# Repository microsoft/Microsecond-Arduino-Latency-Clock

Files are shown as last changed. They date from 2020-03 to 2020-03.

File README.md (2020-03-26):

# Microsecond Arduino Due Code and Schematics

Microsecond Arduino Due Code and Schematics accompanying the paper presented in IEEE VR 2020 "Measuring System Visual Latency through Cognitive Latency on Video See-Through AR devices" [1]
https://www.microsoft.com/en-us/research/publication/measuring-system-visual-latency-through-cognitive-latency-on-video-see-through-ar-devices/

The clock starts from zero and continues to displayelapsed time since the device was powered on. The LED turn-on andturn-off time is sub-microsecond [2], therefore we know that ourclock is sufficient for at least 0.1 millisecond measurements as theLEDs turn on and off faster than we are updating the digit segments.

This clock can be then visualized through an external observer [3] using high refresh cameras.

[1] Gruen, R., Ofek, E., Steed, A., Gal, R., Sinclair, M., & Gonzalez-Franco, M. (2020) Measuring System Visual Latency through Cognitive Latency on Video See-Through AR devices. IEEE VR 2020

[2] Lee,T. P. (1975) Effect of junction capacitance on the rise time of led’s and onthe turn-on delay of injection lasers. The Bell System Technical Journal,54(1):53–68, Jan 1975.

[3] Wu, W., Dong, Y., & Hoover, A. (2013). Measuring digital system latency from sensing to actuation at continuous 1-ms resolution. Presence: Teleoperators and Virtual Environments, 22(1), 20-35.

Schematics created with Eagle v 9.5.2.



# Contributing

This project welcomes contributions and suggestions.  Most contributions require you to agree to a
Contributor License Agreement (CLA) declaring that you have the right to, and actually do, grant us
the rights to use your contribution. For details, visit https://cla.opensource.microsoft.com.

When you submit a pull request, a CLA bot will automatically determine whether you need to provide
a CLA and decorate the PR appropriately (e.g., status check, comment). Simply follow the instructions
provided by the bot. You will only need to do this once across all repos using our CLA.

This project has adopted the [Microsoft Open Source Code of Conduct](https://opensource.microsoft.com/codeofconduct/).
For more information see the [Code of Conduct FAQ](https://opensource.microsoft.com/codeofconduct/faq/) or
contact [opencode@microsoft.com](mailto:opencode@microsoft.com) with any additional questions or comments.

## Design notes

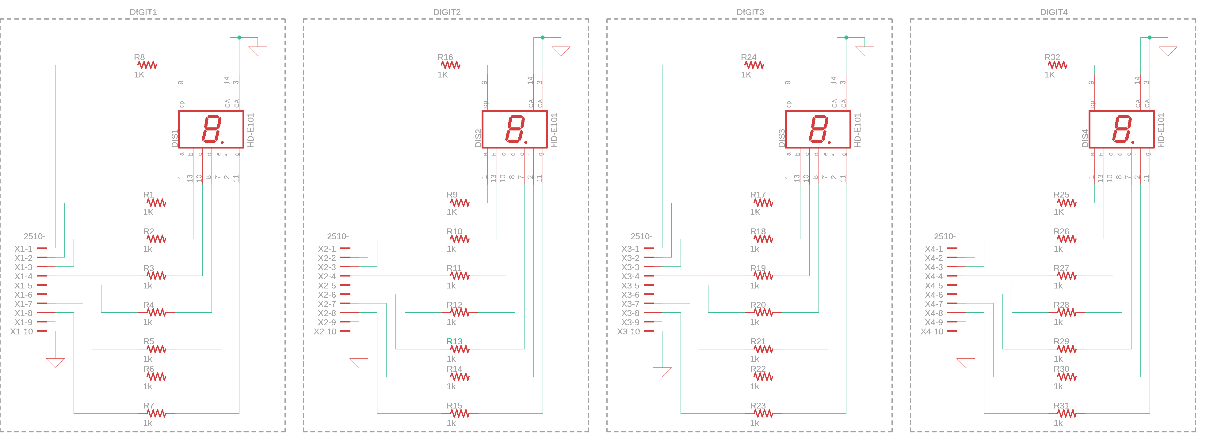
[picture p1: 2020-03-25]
Microsecond clock LEDs - Circuit Diagram.png

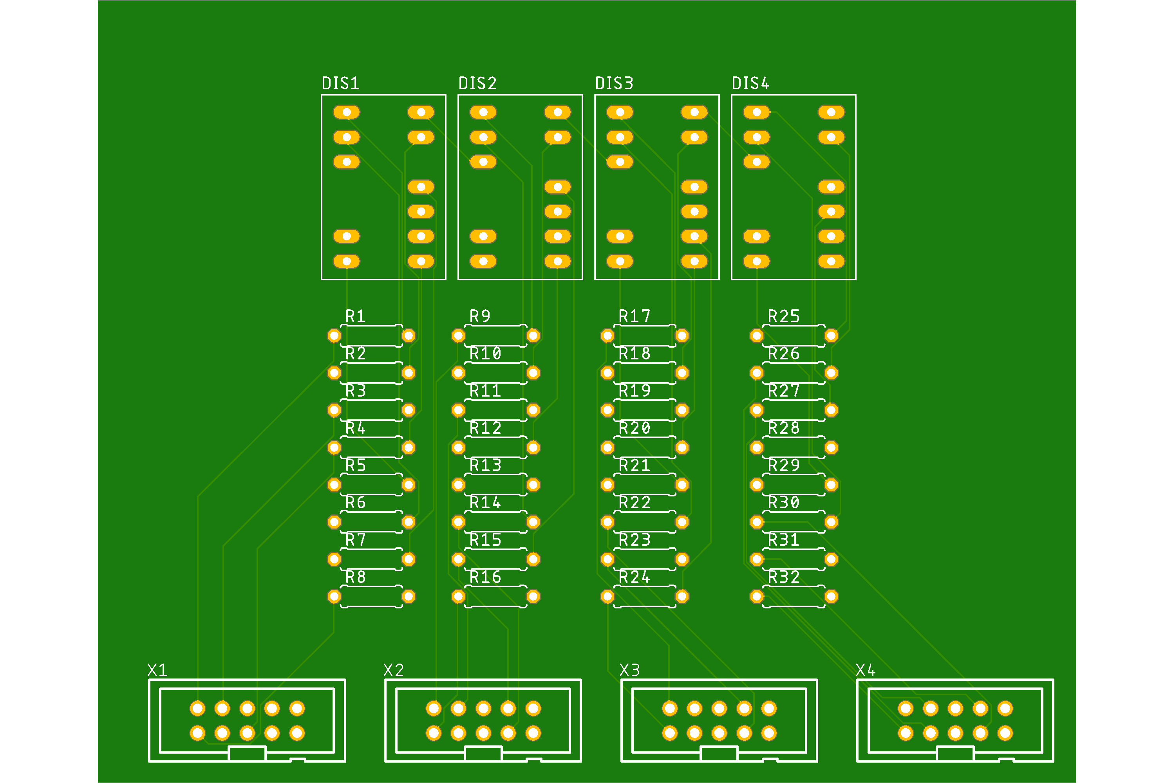
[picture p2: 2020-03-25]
Microsecond clock LEDs - PCB.png

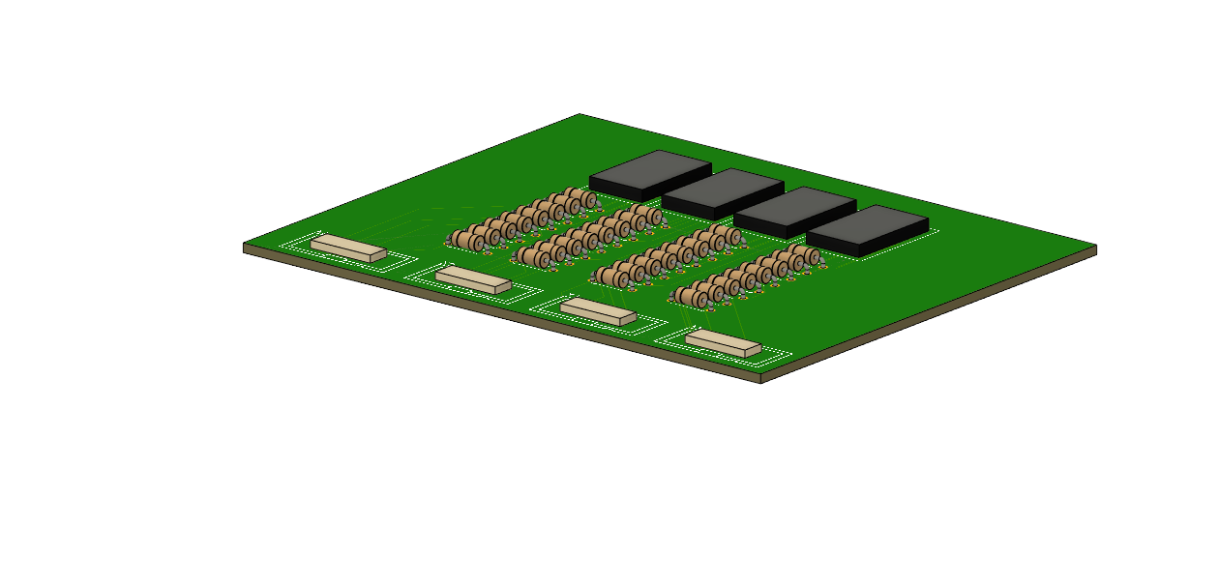
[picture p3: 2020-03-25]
Microsecond clock LEDs - CAD Rendering.png

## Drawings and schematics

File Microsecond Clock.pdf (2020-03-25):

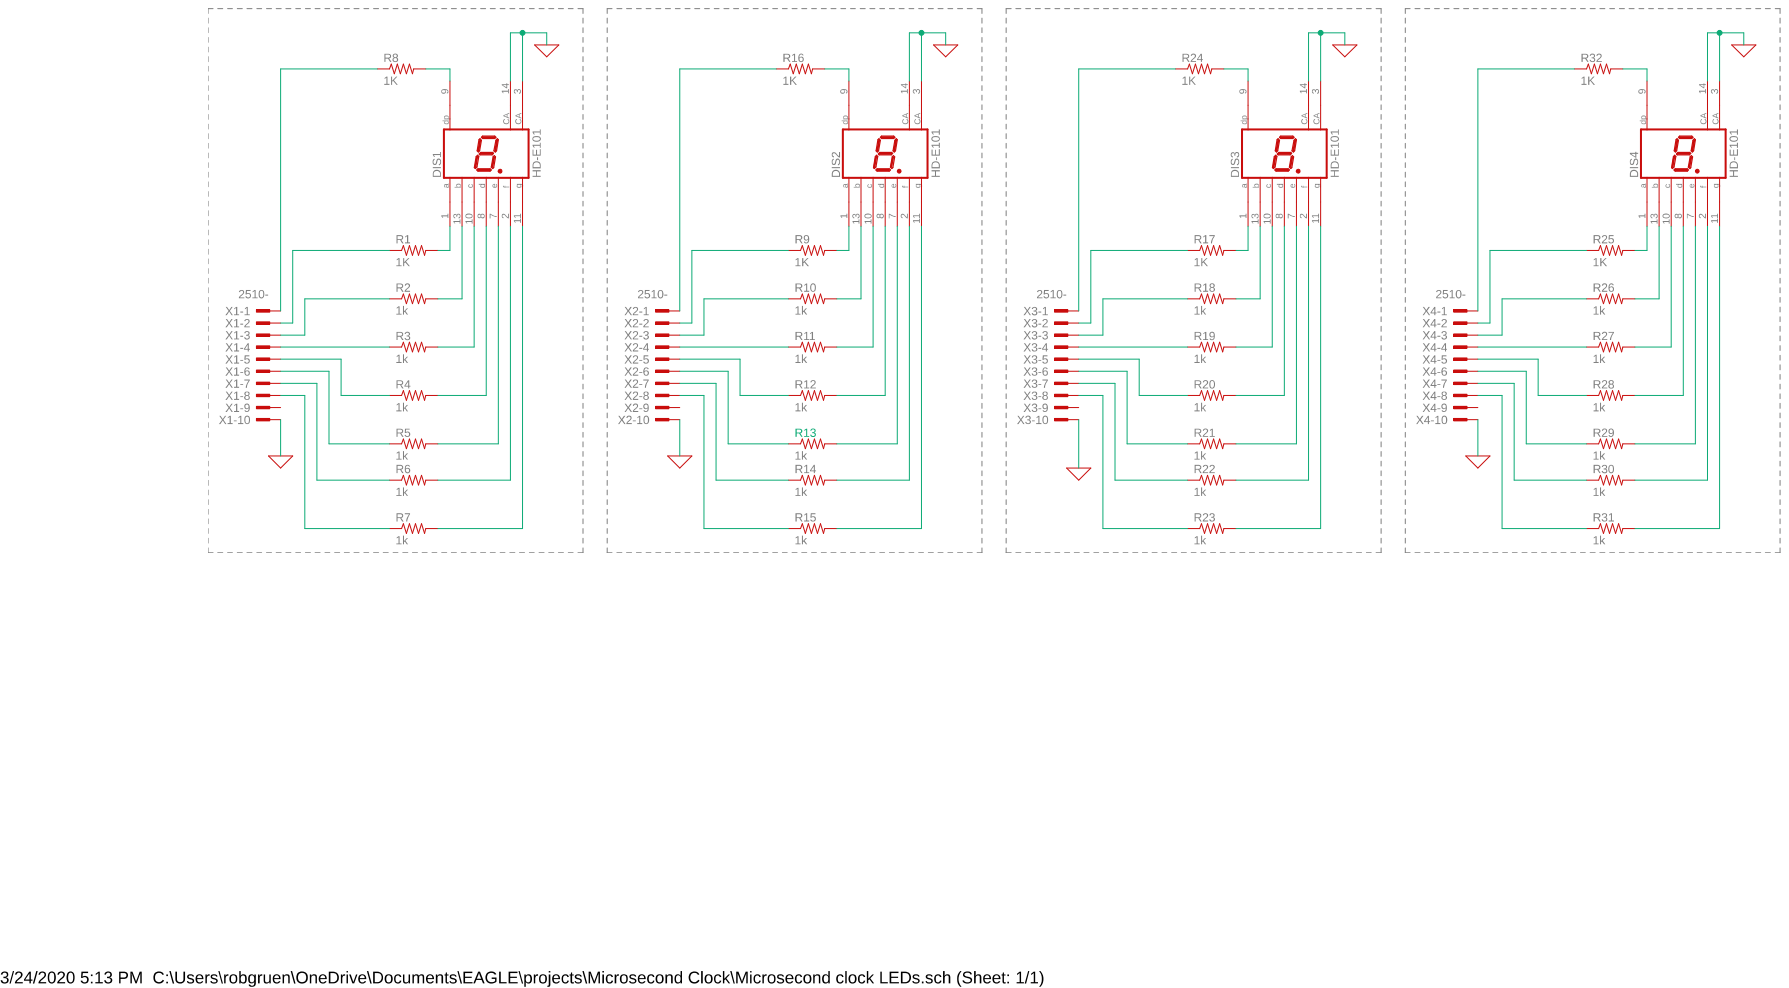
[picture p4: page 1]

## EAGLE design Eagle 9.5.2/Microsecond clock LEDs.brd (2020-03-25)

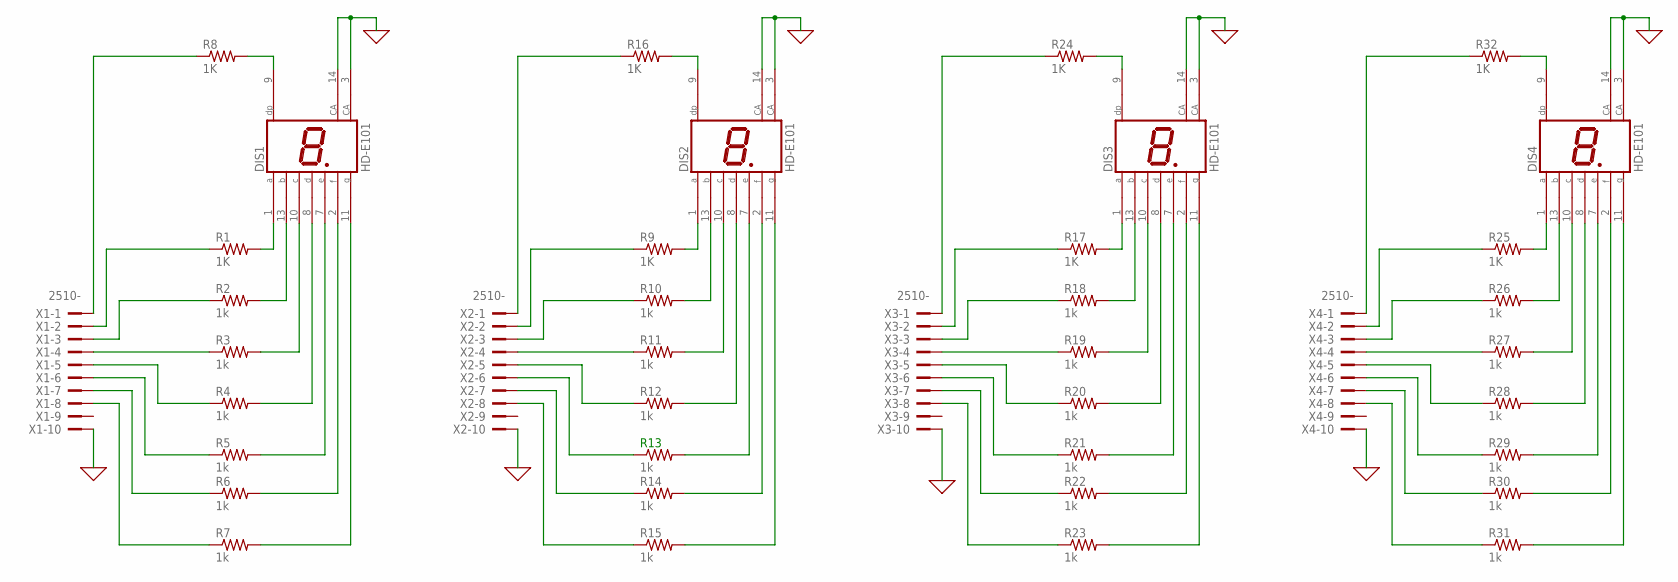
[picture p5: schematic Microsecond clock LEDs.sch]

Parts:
DIS1, DIS2, DIS3, DIS4: HD-E101; HDSP-I
R1, R8, R9, R16, R17, R24, R25, R32: 1K; 0207/7
R2, R3, R4, R5, R6, R7, R10, R11, R12, R13, R14, R15, R18, R19, R20, R21, R22, R23, R26, R27, R28, R29, R30, R31: 1k; 0207/7
X1, X2, X3, X4: 2510-; PAK100/2500-10

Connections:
0: DIS1.3 (CA), DIS1.14 (CA), DIS2.3 (CA), DIS2.14 (CA), DIS3.3 (CA), DIS3.14 (CA), DIS4.3 (CA), DIS4.14 (CA), X1.10, X2.10, X3.10, X4.10
unnamed: DIS1.1 (A), R1.2
unnamed: DIS1.13 (B), R2.2
unnamed: DIS1.10 (C), R3.2
unnamed: DIS1.8 (D), R4.2
unnamed: DIS1.7 (E), R5.2
unnamed: DIS1.2 (F), R6.2
unnamed: DIS1.11 (G), R7.2
unnamed: DIS1.9 (DP), R8.2
unnamed: R8.1, X1.1
unnamed: R1.1, X1.2
unnamed: R2.1, X1.3
unnamed: R3.1, X1.4
unnamed: R4.1, X1.5
unnamed: R5.1, X1.6
unnamed: R6.1, X1.7
unnamed: R7.1, X1.8
unnamed: DIS2.1 (A), R9.2
unnamed: DIS2.13 (B), R10.2
unnamed: DIS2.10 (C), R11.2
unnamed: DIS2.8 (D), R12.2
unnamed: DIS2.7 (E), R13.2
unnamed: DIS2.2 (F), R14.2
unnamed: DIS2.11 (G), R15.2
unnamed: DIS2.9 (DP), R16.2
unnamed: R16.1, X2.1
unnamed: R9.1, X2.2
unnamed: R10.1, X2.3
unnamed: R11.1, X2.4
unnamed: R12.1, X2.5
unnamed: R13.1, X2.6
unnamed: R14.1, X2.7
unnamed: R15.1, X2.8
unnamed: DIS3.1 (A), R17.2
unnamed: DIS3.13 (B), R18.2
unnamed: DIS3.10 (C), R19.2
unnamed: DIS3.8 (D), R20.2
unnamed: DIS3.7 (E), R21.2
unnamed: DIS3.2 (F), R22.2
unnamed: DIS3.11 (G), R23.2
unnamed: DIS3.9 (DP), R24.2
unnamed: R24.1, X3.1
unnamed: R17.1, X3.2
unnamed: R18.1, X3.3
unnamed: R19.1, X3.4
unnamed: R20.1, X3.5
unnamed: R21.1, X3.6
unnamed: R22.1, X3.7
unnamed: R23.1, X3.8
unnamed: DIS4.1 (A), R25.2
unnamed: DIS4.13 (B), R26.2
unnamed: DIS4.10 (C), R27.2
unnamed: DIS4.8 (D), R28.2
unnamed: DIS4.7 (E), R29.2
unnamed: DIS4.2 (F), R30.2
unnamed: DIS4.11 (G), R31.2
unnamed: DIS4.9 (DP), R32.2
unnamed: R32.1, X4.1
unnamed: R25.1, X4.2
unnamed: R26.1, X4.3
unnamed: R27.1, X4.4
unnamed: R28.1, X4.5
unnamed: R29.1, X4.6
unnamed: R30.1, X4.7
unnamed: R31.1, X4.8

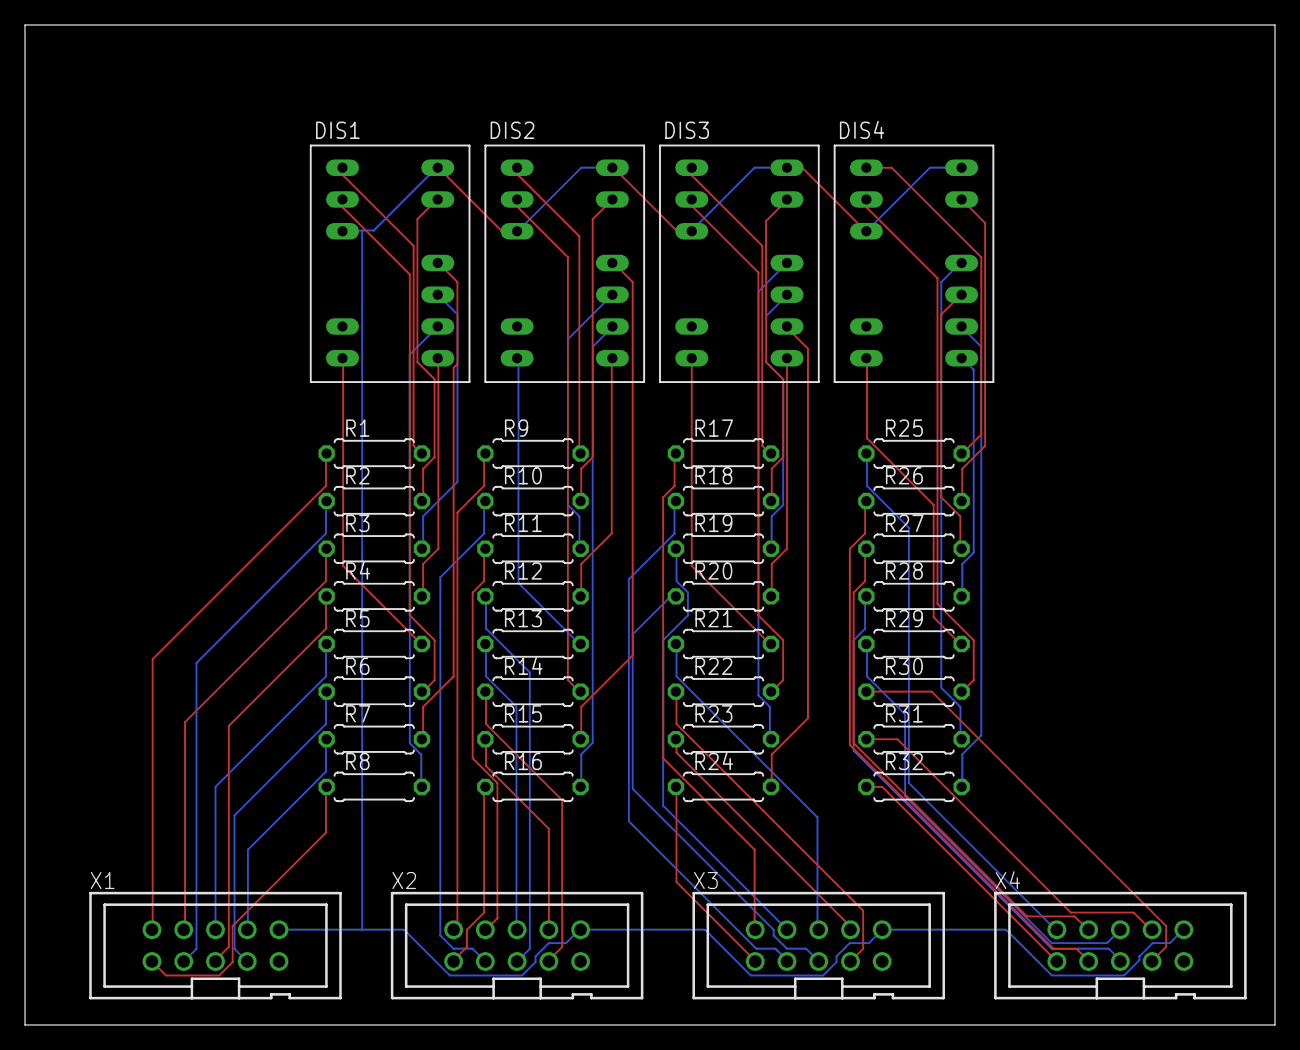
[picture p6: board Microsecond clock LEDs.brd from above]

Board: 2 copper layers, 100.0 x 80.0 mm, 40 parts (0 on the bottom side), 65 nets.

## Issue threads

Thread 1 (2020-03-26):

add software and version for the creation of schematics, pcbs, and cad designs.

mxochicale, 2020-03-26:
HI @margonzalezfranco

Very nice work! To make a more reproducible work, perhaps you can add the software and version used to create your schematics, pcbs, and cad designs.

Miguel

robgruen, 2020-03-26:
I just added the project files for the schematic, pcb, and cad designs.  Created with Eagle v9.5.2.

margonzalezfranco, 2020-03-26:
Hi We have added
the project files for the schematic, pcb, and cad designs. Created with Eagle v9.5.2.

Sent from my phone

On Mar 26, 2020, at 6:20 AM, Miguel Xochicale <notifications@github.com> wrote:

HI @margonzalezfranco<https://nam06.safelinks.protection.outlook.com/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>

Very nice work! To make a more reproducible work, perhaps you can add the software and version used to create your schematics, pcbs, and cad designs.

Miguel

—
You are receiving this because you were mentioned.
Reply to this email directly, view it on GitHub<https://nam06.safelinks.protection.outlook.com/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>, or unsubscribe<https://nam06.safelinks.protection.outlook.com/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>.

Closed 2020-03-26.

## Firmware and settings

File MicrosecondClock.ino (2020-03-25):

//            A
//  ========================
//  =                      =
//  =                      =
//  =                      =
//F =                      = B
//  =                      =
//  =                      =
//  =          G           =
//  ========================
//  =                      =
//  =                      =
//  =                      =
//E =                      = C
//  =                      =
//  =                      =
//  =          D           =   ==
//  ========================   ==  DP

const int DIGIT_1_SEGMENT_A = 31;
const int DIGIT_1_SEGMENT_B = 37;
const int DIGIT_1_SEGMENT_C = 33;
const int DIGIT_1_SEGMENT_D = 34;
const int DIGIT_1_SEGMENT_E = 36;
const int DIGIT_1_SEGMENT_F = 30;
const int DIGIT_1_SEGMENT_G = 35;
const int DIGIT_1_SEGMENT_DP = 32;

const int DIGIT_2_SEGMENT_A = 23;
const int DIGIT_2_SEGMENT_B = 29;
const int DIGIT_2_SEGMENT_C = 25;
const int DIGIT_2_SEGMENT_D = 26;
const int DIGIT_2_SEGMENT_E = 28;
const int DIGIT_2_SEGMENT_F = 22;
const int DIGIT_2_SEGMENT_G = 27;
const int DIGIT_2_SEGMENT_DP = 24;

const int DIGIT_3_SEGMENT_A = 39;
const int DIGIT_3_SEGMENT_B = 45;
const int DIGIT_3_SEGMENT_C = 41;
const int DIGIT_3_SEGMENT_D = 42;
const int DIGIT_3_SEGMENT_E = 44;
const int DIGIT_3_SEGMENT_F = 38;
const int DIGIT_3_SEGMENT_G = 43;
const int DIGIT_3_SEGMENT_DP = 40;

const int DIGIT_4_SEGMENT_A = 47;
const int DIGIT_4_SEGMENT_B = 53;
const int DIGIT_4_SEGMENT_C = 49;
const int DIGIT_4_SEGMENT_D = 50;
const int DIGIT_4_SEGMENT_E = 52;
const int DIGIT_4_SEGMENT_F = 46;
const int DIGIT_4_SEGMENT_G = 51;
const int DIGIT_4_SEGMENT_DP = 48;


int first_digit[8] = { DIGIT_1_SEGMENT_A, DIGIT_1_SEGMENT_B, DIGIT_1_SEGMENT_C, DIGIT_1_SEGMENT_D, DIGIT_1_SEGMENT_E, DIGIT_1_SEGMENT_F, DIGIT_1_SEGMENT_G, DIGIT_1_SEGMENT_DP };
int second_digit[8] = { DIGIT_2_SEGMENT_A, DIGIT_2_SEGMENT_B, DIGIT_2_SEGMENT_C, DIGIT_2_SEGMENT_D, DIGIT_2_SEGMENT_E, DIGIT_2_SEGMENT_F, DIGIT_2_SEGMENT_G, DIGIT_2_SEGMENT_DP };
int third_digit[8] = { DIGIT_3_SEGMENT_A, DIGIT_3_SEGMENT_B, DIGIT_3_SEGMENT_C, DIGIT_3_SEGMENT_D, DIGIT_3_SEGMENT_E, DIGIT_3_SEGMENT_F, DIGIT_3_SEGMENT_G, DIGIT_3_SEGMENT_DP };
int fourth_digit[8] = { DIGIT_4_SEGMENT_A, DIGIT_4_SEGMENT_B, DIGIT_4_SEGMENT_C, DIGIT_4_SEGMENT_D, DIGIT_4_SEGMENT_E, DIGIT_4_SEGMENT_F, DIGIT_4_SEGMENT_G, DIGIT_4_SEGMENT_DP };

int number_allOn[7] = { 1, 1, 1, 1, 1, 1, 1 };
int number_allOff[7] = { 0, 0, 0, 0, 0, 0, 0 };
int number_0[7] = { 1, 1, 1, 1, 1, 1, 0 };
int number_1[7] = { 0, 1, 1, 0, 0, 0, 0 };
int number_2[7] = { 1, 1, 0, 1, 1, 0, 1 };
int number_3[7] = { 1, 1, 1, 1, 0, 0, 1 };
int number_4[7] = { 0, 1, 1, 0, 0, 1, 1 };
int number_5[7] = { 1, 0, 1, 1, 0, 1, 1 };
int number_6[7] = { 1, 0, 1, 1, 1, 1, 1 };
int number_7[7] = { 1, 1, 1, 0, 0, 0, 0 };
int number_8[7] = { 1, 1, 1, 1, 1, 1, 1 };
int number_9[7] = { 1, 1, 1, 1, 0, 1, 1 };

int count = 0;
bool ledState = false;
char buffer[128];
int DEBUG = 1;
int lastTimestamp = 0;

void setup() {

  Serial.begin(115200);
  
  // put your setup code here, to run once:
  pinMode(LED_BUILTIN, OUTPUT);

  Serial.println("Setting up first digit LED IOs");
  pinMode(DIGIT_1_SEGMENT_A, OUTPUT);
  pinMode(DIGIT_1_SEGMENT_B, OUTPUT);
  pinMode(DIGIT_1_SEGMENT_C, OUTPUT);
  pinMode(DIGIT_1_SEGMENT_D, OUTPUT);
  pinMode(DIGIT_1_SEGMENT_E, OUTPUT);
  pinMode(DIGIT_1_SEGMENT_F, OUTPUT);
  pinMode(DIGIT_1_SEGMENT_G, OUTPUT);
  pinMode(DIGIT_1_SEGMENT_DP, OUTPUT);

  Serial.println("Setting up second digit LED IOs");
  pinMode(DIGIT_2_SEGMENT_A, OUTPUT);
  pinMode(DIGIT_2_SEGMENT_B, OUTPUT);
  pinMode(DIGIT_2_SEGMENT_C, OUTPUT);
  pinMode(DIGIT_2_SEGMENT_D, OUTPUT);
  pinMode(DIGIT_2_SEGMENT_E, OUTPUT);
  pinMode(DIGIT_2_SEGMENT_F, OUTPUT);
  pinMode(DIGIT_2_SEGMENT_G, OUTPUT);
  pinMode(DIGIT_2_SEGMENT_DP, OUTPUT);

  Serial.println("Setting up third digit LED IOs");
  pinMode(DIGIT_3_SEGMENT_A, OUTPUT);
  pinMode(DIGIT_3_SEGMENT_B, OUTPUT);
  pinMode(DIGIT_3_SEGMENT_C, OUTPUT);
  pinMode(DIGIT_3_SEGMENT_D, OUTPUT);
  pinMode(DIGIT_3_SEGMENT_E, OUTPUT);
  pinMode(DIGIT_3_SEGMENT_F, OUTPUT);
  pinMode(DIGIT_3_SEGMENT_G, OUTPUT);
  pinMode(DIGIT_3_SEGMENT_DP, OUTPUT);
  
  Serial.println("Setting up fourth digit LED IOs");
  pinMode(DIGIT_4_SEGMENT_A, OUTPUT);
  pinMode(DIGIT_4_SEGMENT_B, OUTPUT);
  pinMode(DIGIT_4_SEGMENT_C, OUTPUT);
  pinMode(DIGIT_4_SEGMENT_D, OUTPUT);
  pinMode(DIGIT_4_SEGMENT_E, OUTPUT);
  pinMode(DIGIT_4_SEGMENT_F, OUTPUT);
  pinMode(DIGIT_4_SEGMENT_G, OUTPUT);
  pinMode(DIGIT_4_SEGMENT_DP, OUTPUT);
}

void loop() {
  // put your main code here, to run repeatedly:


  int m = micros();
  //int m = millis();
  int s = m / 1000;

  if (m - lastTimestamp > 500) {
    ledState = !ledState;
    digitalWrite(LED_BUILTIN, ledState);
    lastTimestamp = m;
  }

  //sprintf(buffer, "s: %d\tm: %d", s, m);
  //Serial.println(buffer);

  // this is if you want to show hundreds of millseconds and hundreds of microseconds
  // hundreds of milliseconds 
  SetNumber(1, (s / 100) % 10, false);

  // tends of milliseconds
  SetNumber(2, (s / 10 % 10), false);      

  // thousandths of second (millisecond)
  SetNumber(3, s % 10, true);

  // tenths of milliseconds (hundreds of microseconds)
  SetNumber(4, (m / 100) % 10, false);

//  // this is if you want to show tens of milliseconds and tens of micro seconds
//  // tens 
//  if (s >= 100) {
//      SetNumber(1, (s / 10 % 10), false);
//  }    
//  else {  
//    SetNumber(1, s / 10, false);      
//  }
//
//  // singles
//  SetNumber(2, s % 10, true);
//
//  // tenths
//  SetNumber(3, (m / 100) % 10, false);
//
//  // hundredths
//  SetNumber(4, (m / 10) % 10, false);
}

// Set the number on the LCD panel
void SetNumber(int digit, int number, bool decimalPoint) {

  int* digit_pins;

  switch(digit) {
    case 1: digit_pins = first_digit; break;
    case 2: digit_pins = second_digit; break;
    case 3: digit_pins = third_digit; break;
    case 4: digit_pins = fourth_digit; break;
  }

  //sprintf (buffer, "SetNumber - Digit: %d\tNumber: %d\tDecimal: %s", digit, number, decimalPoint ? "true" : "false" );
  //Serial.println(buffer);
 
  for (int i = 0; i < 7; i++) {
    digitalWrite(digit_pins[i], !GetSegmentStateForNumber(number, i));
  }

  // turn on the decimal?
  digitalWrite(digit_pins[7], !decimalPoint);
}

bool GetSegmentStateForNumber(int number, int segment_number) {
  switch(number) {
    case 0:
      return number_0[segment_number];
      break;
    case 1:
      return number_1[segment_number];
      break;
    case 2:
      return number_2[segment_number];
      break;
    case 3:
      return number_3[segment_number];
      break;
    case 4:
      return number_4[segment_number];
      break;
    case 5:
      return number_5[segment_number];
      break;
    case 6:
      return number_6[segment_number];
      break;
    case 7:
      return number_7[segment_number];
      break;
    case 8:
      return number_8[segment_number];
      break;
    case 9:
      return number_9[segment_number];
      break;
    case -1:
      return number_allOn[segment_number];
      break;    
    default:
      return number_allOff[segment_number];
      break;
      
  }
}
